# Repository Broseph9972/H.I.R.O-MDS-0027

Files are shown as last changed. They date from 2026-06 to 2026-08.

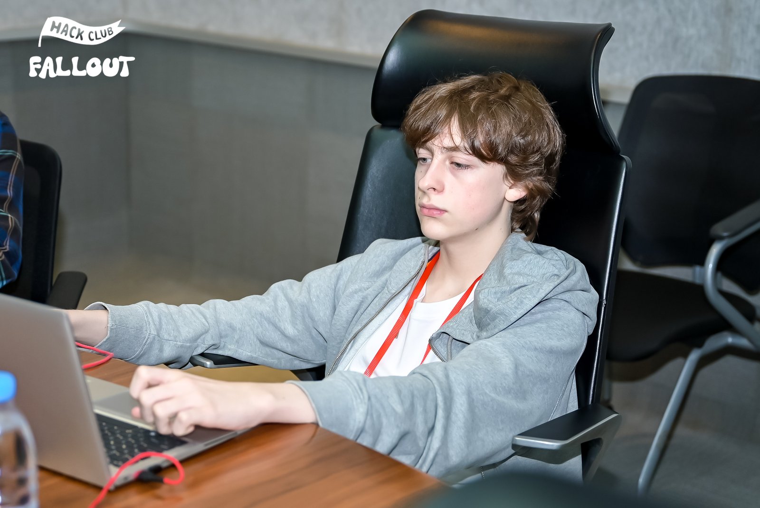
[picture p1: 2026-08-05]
3D/3d Files/2_1600_3000_gif.jpg

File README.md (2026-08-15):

# H.I.R.O-MDS-0027
a music video faithful mp3 player based on the H.I.R.O from good kid Music videos. built for Hack club fallout in about 2 weeks. My favorite Hardware project yet
---
<p align="center">
NewHiroZine


</p>
<p align="center">
  
  
  
</p>

I unironically listened to almost exclusively good kid while making this project.

---
## Why?
I've always loved good kid, and i was bored at night watching some of their music videos, and saw a scene of the H.I.R.O taken apart with a soldering iron,[^1] and realised, i could probably make that.
I cant explain how to use it yet, as i have not built it yet, but it should go something like select a song or playlist, and itll play said song or playlist. (duh)
This is my first project where i'm not very concerned about budget, as it isnt completely practical, it just needs to look as close as possible to the original. I did get rid of the arms and legs because it would make it annoying to use imho.

# Assembly

## Read through this before starting just for understanding.

  1. Solder Parts Onto the PCB. As there are many SMD Components and small capacitors, reflow soldering is recommended. Use long header pins for the screen DO NOT SOLDER THE SCREEN TO THE PCB YET.
  2. If any Through Hole parts poke into the case, like the speaker, use pliers or something to take them off. there should be indents in the case for them though.
  3. Place the PCB Onto the Main Casing. If it dosent fit, just sand the part until it does.
  4. Screw In the screen to the 4 square brackets on the main casing with M3x14 Screws.
  5. Solder the Screen Connector pins to the screen. (if gpio are short, im so sorry but i would just desolder and use jumper wires.)
  6. Plug in the battery to the JST Connector. Slide it wherever it fits, i reccomend under the screen. any lipo battery should work.
  7. (vid isnt accurate) Slide the buttons into place so that the lip dosent allow it to get pushed out.
  8. Place the Lid on Top, Turn the main casing over, and screw in 3 M3x14 Screws.
  9. (Optional) Paint it! it looks so much cooler Painted. I highly reccomend this.

### Assembly Video (its really bad)
https://github.com/user-attachments/assets/d8cce7da-2541-4a06-ba8f-5a0993665533

# Usage
The H.I.R.O has 3 inputs.
1. Button 1
2. Button 2
3. Clicky Knob

Spin the knob to cycle through the options on the screen. Click the knob to select.
Button 1 is for skipping to the next song. Hold to skip past 10s at a time in a specific song.
Button 2 is for rewinding. Click once to go to the last song. click twice to restart the song. Hold to go back 10s at a time in the song. 
# Setup
  1. Flash the Firmware for the MP3 Using arduino IDE or whichever ide you prefer
  2. Insert MicroSD Card With Music on it in Mp3 (or FLAC?) Format.
  3. Play your Music!

## Warning:
Theres a bug where the lid has a huge object inside it when 3d printing, just delete it in your slicer. i dunno why this happens.

# Bill of Materials

| Name | Qty | Reference(s) | Price (USD) | Comments | Link |
|---|-----|---|---|---|---|
| Seeed XIAO ESP32-S3 Plus | 1 | U1 | $7.59 | Main MCU module. SMD footprint (castellated). Source direct from Seeed for genuine part. | [Link](https://www.seeedstudio.com/Seeed-Studio-XIAO-ESP32S3-Plus-p-6361.html) |
| PCM5102A DAC (TSSOP-20) | 1 | U2 | $1.11 | Bare IC from LCSC (C107671). I2S DAC driving the 3.5mm headphone jack. | [Link](https://www.lcsc.com/product-detail/C107671.html) |
| MAX98357A Class-D Amplifier (TQFN-16) | 1 | U3 | $2.00 | Bare TQFN-16 3x3mm IC — NOT a breakout module. Check LCSC / DigiKey / Mouser for current price. | [Link](https://octopart.com/max98357aete+t-maxim+integrated-33346832) |
| CVS-1708 Speaker | 1 | LS1 | $4.02 | 8Ω 200mW 1.2kHz–20kHz. Same Sky (formerly CUI). DigiKey. | [Link](https://www.digikey.com/en/products/detail/same-sky-formerly-cui-devices/CVS-1708/2791829) |
| Hirose DM3AT-SF-PEJM5 microSD Slot | 1 | J1 | $1.53 | Push-push with card detect. LCSC (C114218). | [Link](https://www.lcsc.com/product-detail/SD-Card-Connectors_HRS-Hirose-DM3AT-SF-PEJM5_C114218.html) |
| CUI SJ-3523-SMT-TR 3.5mm Audio Jack | 1 | J2 | $0.88 | Horizontal SMT stereo TRS jack. DigiKey. | [Link](https://www.digikey.com/en/products/detail/cui-devices/SJ-3523-SMT-TR/281297) |
| 1×8 Pin Header 2.54mm (through-hole) | 1 | J3 | $7.99 | Screen connector for Waveshare LCD. Must use long header pins (see assembly notes). | [Link](https://www.amazon.com/whiteeeen-Break-Away-Header-Straight-Connector/dp/B0B75RKMD2) |
| JST PH S2B-PH-K 2-pin Connector | 1 | J4 | $0.11 | Battery connector. 2.0mm pitch horizontal SMT. | [Link](https://www.digikey.com/en/products/detail/jst-sales-america-inc/S2B-PH-K-S/926626) |
| Omron B3U-3100P-B Side Push Button | 2 | S1 / S2 | $1.17 | SMD side-actuated tactile. DigiKey. ×2 units needed. | [Link](https://www.digikey.com/en/products/detail/omron-electronics-inc-emc-div/B3U-3100P-B/1811780) |
| EC11 Right-Angle Rotary Encoder (w/ switch) | 1 | SW1 | $4.07 | Push-switch + encoder. Right-angle EC11. | [Link](https://www.aliexpress.us/item/3256809185234399.html) |
| Capacitor 10µF 0603 | 4 | C1 / C4 / C5 / C6 | $0.01 | X5R or X7R ceramic decoupling. Order from LCSC. | [Link](https://www.lcsc.com/search?q=10uF+0603) |
| Capacitor 100nF 0603 | 2 | C2 / C3 | $0.01 | X7R ceramic decoupling. Order from LCSC. | [Link](https://www.lcsc.com/search?q=100nF+0603) |
| Resistor 1MΩ 0603 | 1 | R1 | $0.01 | 1% tolerance preferred. Order from LCSC. | [Link](https://www.lcsc.com/search?q=1M+0603+resistor) |
| Waveshare 2.4in LCD Module | 1 | — | $18.99 | 240×320 SPI (ILI9341). Connects to J3 header. Closest size match to original H.I.R.O screen. | [Link](https://www.amazon.com/Waveshare-2-4inch-Display-Resolution-Interface/dp/B08H24H7KX) |
| LiPo Battery 3.7V | 1 | — | $9.99 | Any single-cell LiPo with JST PH 2.0mm connector. Slides under screen in case. 500mAh+ recommended. | [Link](https://www.amazon.com/Battery-Rechargeable-Lithium-Polymer-Connector/dp/B07S84SBV3) |
| M3×14 Socket Head Cap Screws | 7 | — | $6.99 | 4× screen brackets + 3× lid. Stainless steel A2. | [Link](https://a.co/d/00dNH8NP) |
| 3D Printed Main Casing | 1 | — | $0.10 | Print from Cad/ directory. Sand if needed for PCB fit (see assembly notes). | [Link](https://github.com/Broseph9972/H.I.R.O-MDS-0027/tree/main/Cad) |
| 3D Printed Lid | 1 | — | $0.10 | Print from Cad/ directory. 3× M3×14 screw holes. | [Link](https://github.com/Broseph9972/H.I.R.O-MDS-0027/tree/main/Cad) |
| Custom PCB (H.I.R.O) | 1 | — | $7.50 | Fabricate from Pcb/ gerbers. JLCPCB / PCBWay / OSH Park. | [Link](https://github.com/Broseph9972/H.I.R.O-MDS-0027/tree/main/Pcb) |
| Paint (optional) | 1 | — | $0 | Spray paint or acrylic. | — |
| **TOTAL** | — | — | **$75.38** | Qty × unit price across all lines (screws/header counted as pack price; optional paint at $0). | — |

[^1]:From [Eastside](https://www.youtube.com/watch?v=-kVTMlbAywQ) [Wall](https://www.youtube.com/watch?v=HG8WEN3SKVk)[Mimis Delivery Service](https://www.youtube.com/watch?v=hYUvI5Njbbk)

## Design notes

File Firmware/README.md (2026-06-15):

# H.I.R.O Firmware

Firmware for the H.I.R.O MDS-0027 MP3 player (Seeed XIAO ESP32-S3 Plus).

## Build & flash

1. Install **VS Code** + the **PlatformIO IDE** extension.
2. Open this `Firmware/` folder in VS Code (PlatformIO detects `platformio.ini`).
3. Plug in the XIAO over USB-C → click **Upload** (the ✓→ arrow in the PlatformIO toolbar).
4. Open the **Serial Monitor** (115200 baud) to watch boot / SD logs.

## SD card

- Format **FAT32**.
- Put your music in a top-level `/music` folder.
- Supported: **MP3, AAC, M4A, FLAC, WAV, OGG/Vorbis, Opus**.

## Controls

| Input | Action |
|---|---|
| Encoder turn | Volume |
| Encoder click | Play / Pause |
| Side button 1 | Previous track |
| Side button 2 | Next track |
| Hold side button 1 (~0.7 s) | Toggle speaker ↔ headphone |

## Code map

| File | Purpose |
|---|---|
| `src/pins.h` | Pin map (matches the KiCad schematic — single source of truth) |
| `src/LGFX_Config.h` | ST7789 display config (LovyanGFX) |
| `src/Face.h` | Programmatic animated face |
| `src/Player.h` | SD playlist + audio decode + I²S output routing |
| `src/Controls.h` | Buttons + rotary encoder |
| `src/main.cpp` | Wires it all together |

## First-hardware bring-up notes

This compiles, but it has **never run on the real board** (the board doesn't exist yet). Expect to iterate on:

1. **SPI bus sharing (display + SD).** They share SCK/MOSI/MISO. If the screen garbles during card reads, lower `freq_write` in `LGFX_Config.h` and/or the SD clock in `Player.h`.
2. **Display orientation / colors.** `setRotation`, `invert`, and `rgb_order` may need flipping once you can see it.
3. **Speaker/headphone switch.** With no jack-detect wired, output is swapped manually (hold SW1). Verify both DACs sound right.
4. **Button polarity / encoder direction.** If the encoder counts backwards, swap `PIN_ENC_A`/`PIN_ENC_B`.

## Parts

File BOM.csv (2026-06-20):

Name | Qty | Reference(s) | Price (USD) | Comments | Link
Seeed XIAO ESP32-S3 Plus | 1 | U1 | $7.59 | Main MCU module. SMD footprint (castellated). Source direct from Seeed for genuine part. | https://www.seeedstudio.com/Seeed-Studio-XIAO-ESP32S3-Plus-p-6361.html
PCM5102A DAC (TSSOP-20) | 1 | U2 | $1.11 | Bare IC from LCSC (C107671). I2S DAC driving the 3.5mm headphone jack. | https://www.lcsc.com/product-detail/C107671.html
MAX98357A Class-D Amplifier (TQFN-16) | 1 | U3 | $2 | Bare TQFN-16 3x3mm IC — NOT a breakout module. Check LCSC / DigiKey / Mouser for current price. | https://octopart.com/max98357aete+t-maxim+integrated-33346832
CVS-1708 Speaker | 1 | LS1 | $4.02 | 8Ω 200mW 1.2kHz–20kHz. Same Sky (formerly CUI). DigiKey. | https://www.digikey.com/en/products/detail/same-sky-formerly-cui-devices/CVS-1708/2791829
Hirose DM3AT-SF-PEJM5 microSD Slot | 1 | J1 | $1.53 | Push-push with card detect. LCSC (C114218). | https://www.lcsc.com/product-detail/SD-Card-Connectors_HRS-Hirose-DM3AT-SF-PEJM5_C114218.html
CUI SJ-3523-SMT-TR 3.5mm Audio Jack | 1 | J2 | $0.88 | Horizontal SMT stereo TRS jack. DigiKey. | https://www.digikey.com/en/products/detail/cui-devices/SJ-3523-SMT-TR/281297
1×8 Pin Header 2.54mm (through-hole) | 1 | J3 | $7.99 | Screen connector for Waveshare LCD. Must use long header pins (see assembly notes). | https://www.amazon.com/whiteeeen-Break-Away-Header-Straight-Connector/dp/B0B75RKMD2
JST PH S2B-PH-K 2-pin Connector | 1 | J4 | $0.11 | Battery connector. 2.0mm pitch horizontal SMT. Very cheap — order from DigiKey or LCSC. | https://www.digikey.com/en/products/detail/jst-sales-america-inc/S2B-PH-K-S/926626
Omron B3U-3100P-B Side Push Button | 2 | S1 / S2 | $1.17 | SMD side-actuated tactile. DigiKey. ×2 units needed. | https://www.digikey.com/en/products/detail/omron-electronics-inc-emc-div/B3U-3100P-B/1811780
EC11 Right-Angle Rotary Encoder (w/ switch) | 1 | SW1 | $4.07 | Push-switch + encoder. Right-angle EC11. User-sourced AliExpress link. | https://www.aliexpress.us/item/3256809185234399.html
Capacitor 10µF 0603 (×4) | 4 | C1 / C4 / C5 / C6 | $0.01 | X5R or X7R ceramic. Pennies each — order from LCSC. Search C107471 or equivalent. | https://www.lcsc.com/search?q=10uF+0603
Capacitor 100nF 0603 (×2) | 2 | C2 / C3 | $0.01 | X7R ceramic decoupling. Pennies each — order from LCSC. | https://www.lcsc.com/search?q=100nF+0603
Resistor 1MΩ 0603 (×1) | 1 | R1 | 0.01 | 1% tolerance preferred. Pennies each — order from LCSC. | https://www.lcsc.com/search?q=1M+0603+resistor
Waveshare 2.4in LCD Module | 1 | — | $18.99 | 240×320 SPI (ILI9341). Connects to J3 header. Closest size match to original H.I.R.O screen. | https://www.amazon.com/Waveshare-2-4inch-Display-Resolution-Interface/dp/B08H24H7KX
LiPo Battery 3.7V | 1 | — | $9.99 | Any single-cell LiPo with JST PH 2.0mm connector. Slides under screen in case. 500mAh+ recommended. | https://www.amazon.com/Battery-Rechargeable-Lithium-Polymer-Connector/dp/B07S84SBV3
M3×14 Socket Head Cap Screws | 7 | — | $6.99 | 4× screen brackets + 3× lid. Stainless steel A2. | https://a.co/d/00dNH8NP
3D Printed Main Casing | 1 | — | $0.10 | Print from Cad/ directory. Sand if needed for PCB fit (see assembly notes). | https://github.com/Broseph9972/H.I.R.O-MDS-0027/tree/main/Cad
3D Printed Lid | 1 | — | $0.10 | Print from Cad/ directory. 3× M3×14 screw holes. | https://github.com/Broseph9972/H.I.R.O-MDS-0027/tree/main/Cad
Custom PCB (H.I.R.O) | 1 | — | $7.50 | Fabricate from Pcb/ gerbers. JLCPCB / PCBWay / OSH Park. | https://github.com/Broseph9972/H.I.R.O-MDS-0027/tree/main/Pcb
Paint (optional) | 1 | — | $0 | Spray paint or acrylic. | _
TOTAL | — | — | $75.38 | Qty × unit price across all lines (screws/header counted as pack price; optional paint at $0). | __

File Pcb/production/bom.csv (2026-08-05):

Designator | Footprint | Quantity | Value | LCSC Part #
C1, C4, C5, C6 | 0603 | 4 | 10 µF
C2, C3 | 0603 | 2 | 100nF
J1 | microSD_HC_Hirose_DM3AT-SF-PEJM5 | 1 | Micro_SD_Card_Det_Hirose_DM3AT
J2 | Jack_3.5mm_CUI_SJ-3523-SMT_Horizontal | 1 | AudioJack3
J3 | PinHeader_1x08_P2.54mm_Vertical | 1 | Conn_01x08
J4 | JST_PH_S2B-PH-K_1x02_P2.00mm_Horizontal | 1 | Conn_01x02
LS1 | SPKR_CVS-1708 | 1 | CVS-1708
R1 | 0603 | 1 | 1M
S1, S2 | SW_SPST_B3U-3100P | 2 | B3U-3100P-B
SW1 | Right angle EC11 Rotary Encoder | 1 | RotaryEncoder_Switch
U1 | XIAO-ESP32-S3-Plus-SMD | 1 | XIAO-ESP32-S3-Plus-SMD
U2 | TSSOP-20_4.4x6.5mm_P0.65mm | 1 | PCM5102A
U3 | TQFN-16-1EP_3x3mm_P0.5mm_EP1.23x1.23mm | 1 | MAX98357A

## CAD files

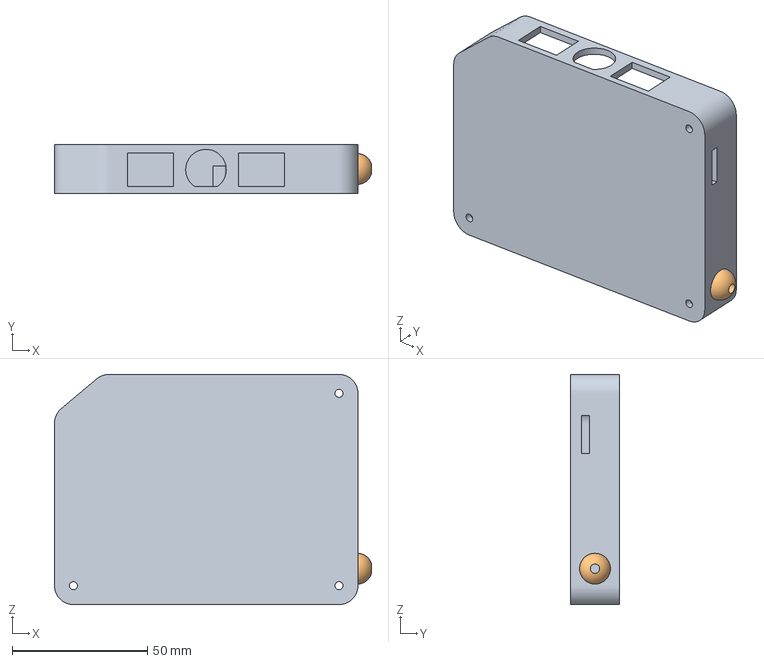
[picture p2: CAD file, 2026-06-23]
3D/3d Files/Main Casing.3mf
117.1 x 18.0 x 85.1 mm

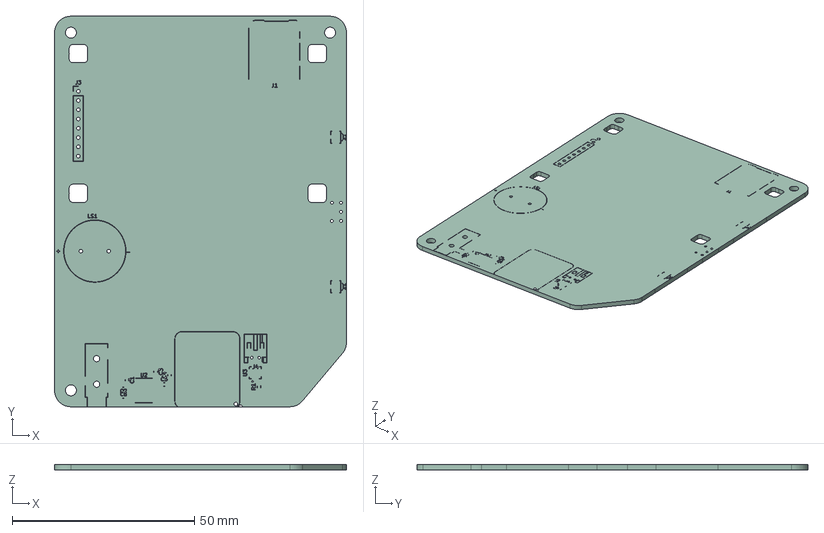
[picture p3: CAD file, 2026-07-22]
3D/3d Files/PCBNoComponents.step
80.1 x 107.1 x 1.58 mm
hiro_silkscreen
hiro_PCB

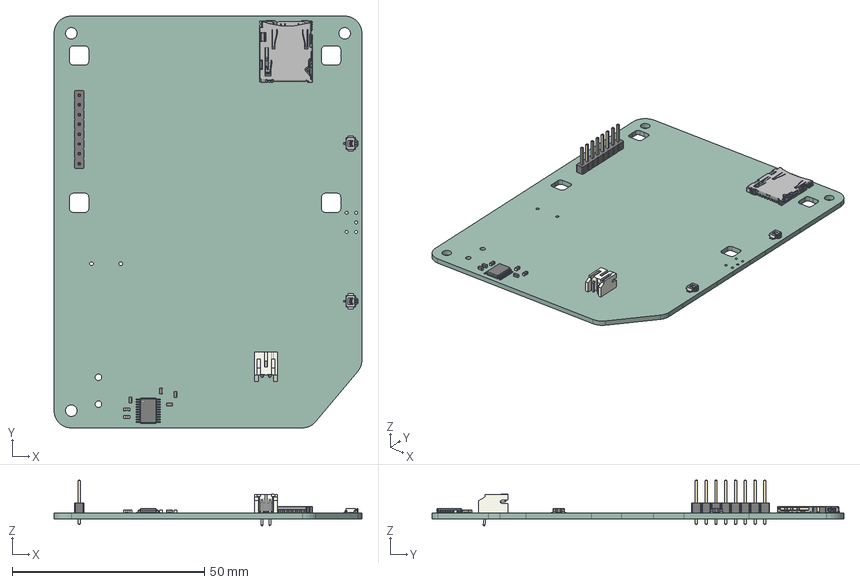
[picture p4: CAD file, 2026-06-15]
Pcb/.step
80.1 x 107.1 x 11.9 mm
TSSOP-20_4.4x6.5mm_P0.65mm
SW_SPST_B3U-3100P x 2
PinHeader_1x08_P254mm_Vertical
C_0603_1608Metric x 6
microSD_HC_Hirose_DM3AT-SF-PEJM5
JST_S2B_PH_K
hiro_PCB

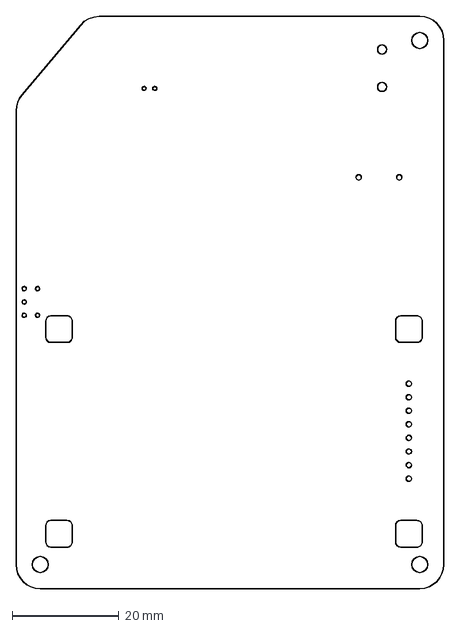
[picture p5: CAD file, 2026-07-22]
3D/3d Files/Pcb outline.dxf
80.1 x 107.1 mm

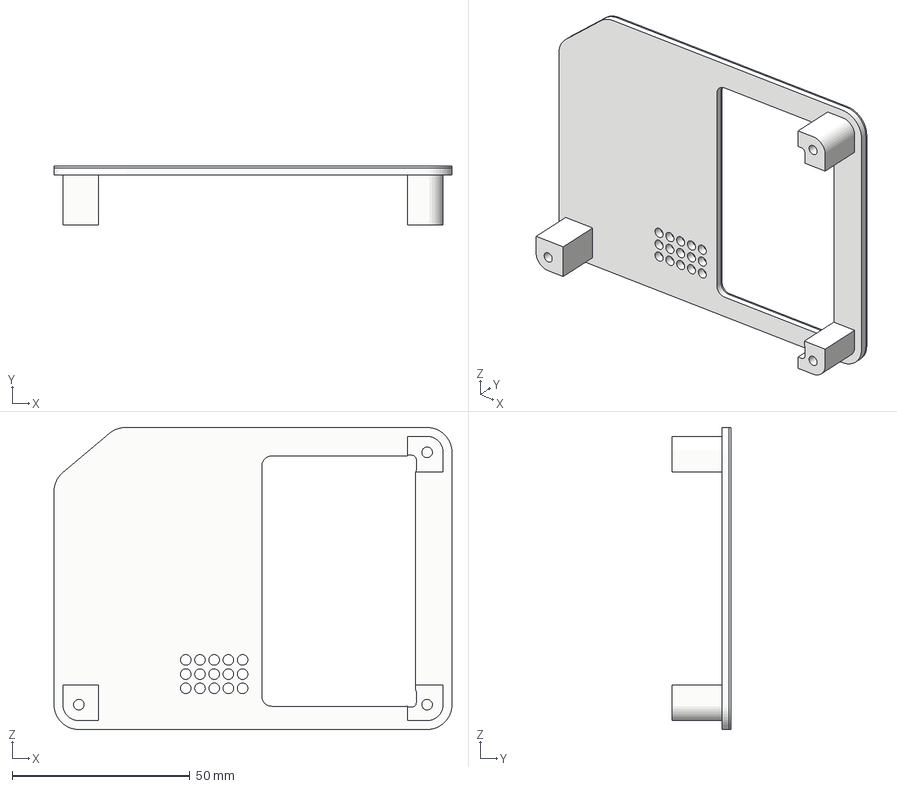
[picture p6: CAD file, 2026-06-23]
3D/3d Files/Lid.3mf
112.1 x 16.5 x 85.1 mm

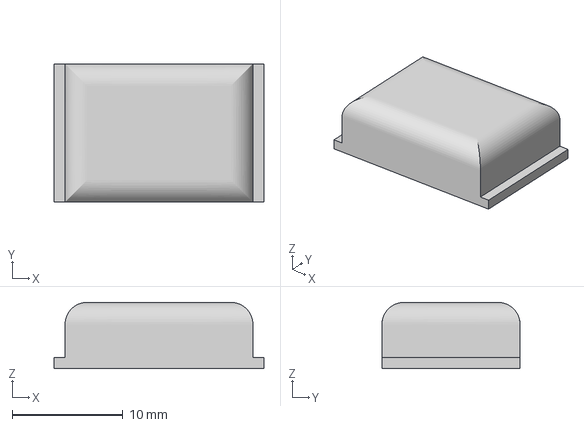
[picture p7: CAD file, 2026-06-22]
3D/3d Files/Side-Button.3mf
19.0 x 12.5 x 6.00 mm

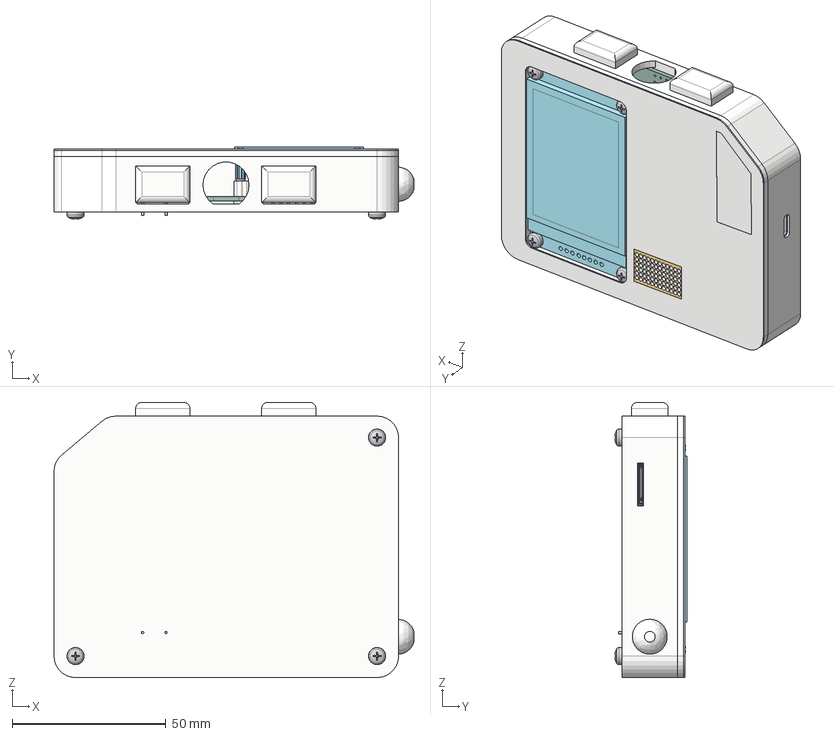
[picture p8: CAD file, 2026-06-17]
3D/3d Files/mds-0027.step
117.1 x 23.5 x 89.5 mm
K01-2
TSSOP-20_4.4x6.5mm_P0.65mm
SW_SPST_B3U-3100P x 2
CVS-1708
PinHeader_1x08_P2.54mm_Vertical
C_0603_1608Metric x 6
microSD_HC_Hirose_DM3AT-SF-PEJM5
JST_PH_S2B-PH-K_1x02_P2.00mm_Horizontal
XIAO-ESP32S3 v2
hiro_silkscreen
hiro_PCB
Main Casing
Side-Button x 2
Lid
UNE-EN ISO 7045 - M3 x 14 - H Steel 4.6 Plain x 4
ISO 7045 - M3 x 14 - H Steel 4.6 Plain x 3

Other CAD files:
3D/Source Files/Lid.f3z
3D/Source Files/Main Casing.f3d
3D/Source Files/Side-Button.f3d
3D/Source Files/mds-0027.f3z

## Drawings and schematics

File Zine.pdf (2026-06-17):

# H.I.R.O MP3 Player

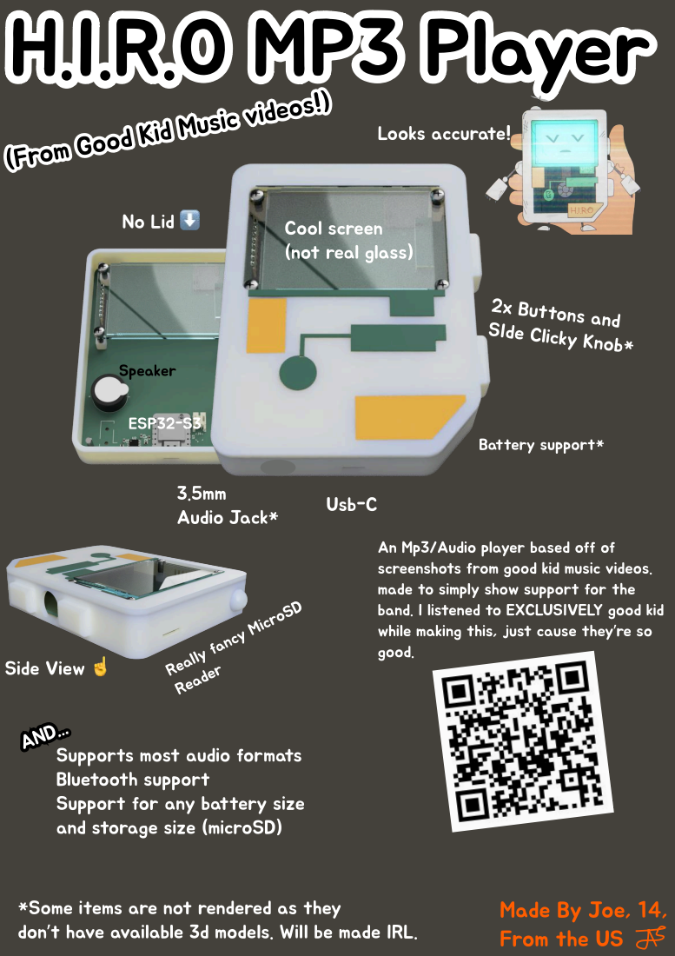
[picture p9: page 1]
Looks accurate!; Side View ☝️; Speaker; ESP32-S3; Audio Jack*; Reader; Usb-C; No Lid ⬇️; Cool screen; 2x Buttons and; Battery support*; AND...

(From Good Kid Music videos!)

(not real glass)

SIde Clicky Knob*

An Mp3/Audio player based off of
screenshots from good kid music videos.
made to simply show support for the
band. I listened to EXCLUSIVELY good kid
while making this, just cause they’re so
good.

Really fancy MicroSD

Supports most audio formats
Bluetooth support
Support for any battery size
and storage size (microSD)

*Some items are not rendered as they
don’t have available 3d models. Will be made IRL.

Made By Joe, 14,
From the US

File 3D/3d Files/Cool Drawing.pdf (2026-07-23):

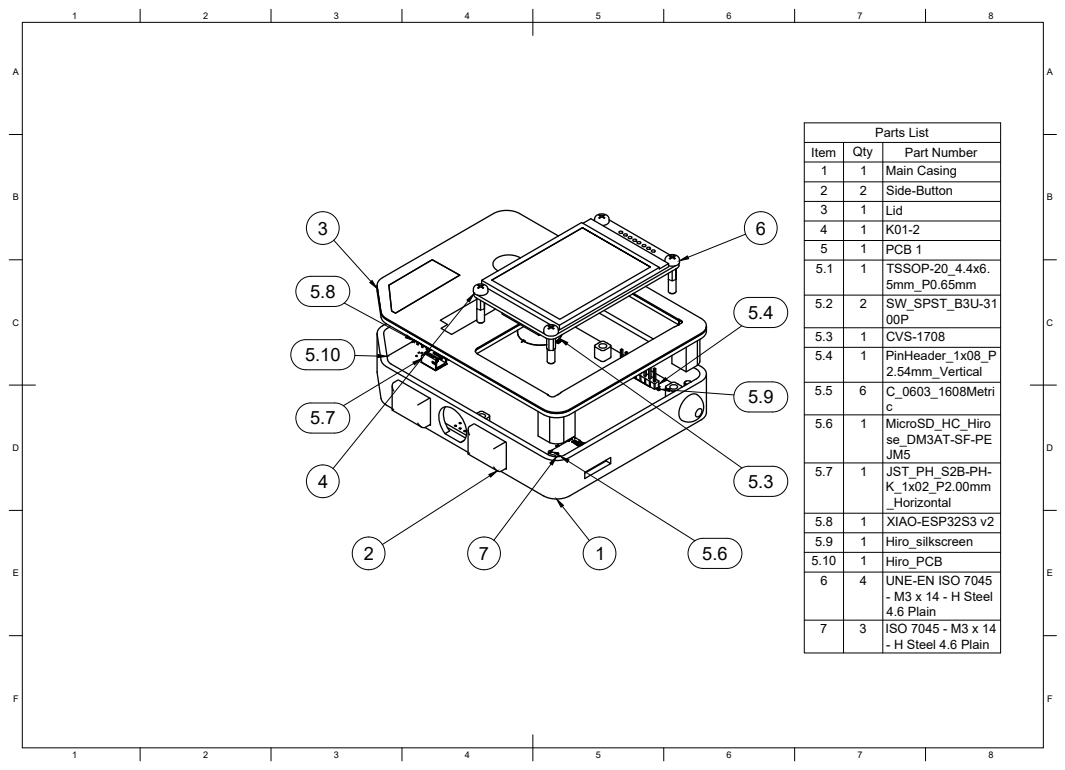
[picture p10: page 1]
8 BCDEF; ABCDEF; Parts List; Item; Qty; Part Number 1; Main Casing 2; Side-Button 3; Lid 4; PCB 1

5.1 | 1 | TSSOP-20_4.4x6. 5mm_P0.65mm

5.2 | 2 | SW_SPST_B3U-31 00P

5.3 | 1 | CVS-1708
5.4 | 1 | PinHeader_1x08_P 2.54mm_Vertical

5.5 | 6 | C_0603_1608Metri c

5.6 | 1 | MicroSD_HC_Hiro se_DM3AT-SF-PE JM5

5.7 | 1 | JST_PH_S2B-PH-K_1x02_P2.00mm _Horizontal

5.8 | 1 | XIAO-ESP32S3 v2
5.9 | 1 | Hiro_silkscreen
5.10 | 4 1 | Hiro_PCB 6 UNE-EN ISO 7045

3 | - M3 x 14 - H Steel ISO 7045 - M3 x 14 4.6 Plain 7

- H Steel 4.6 Plain

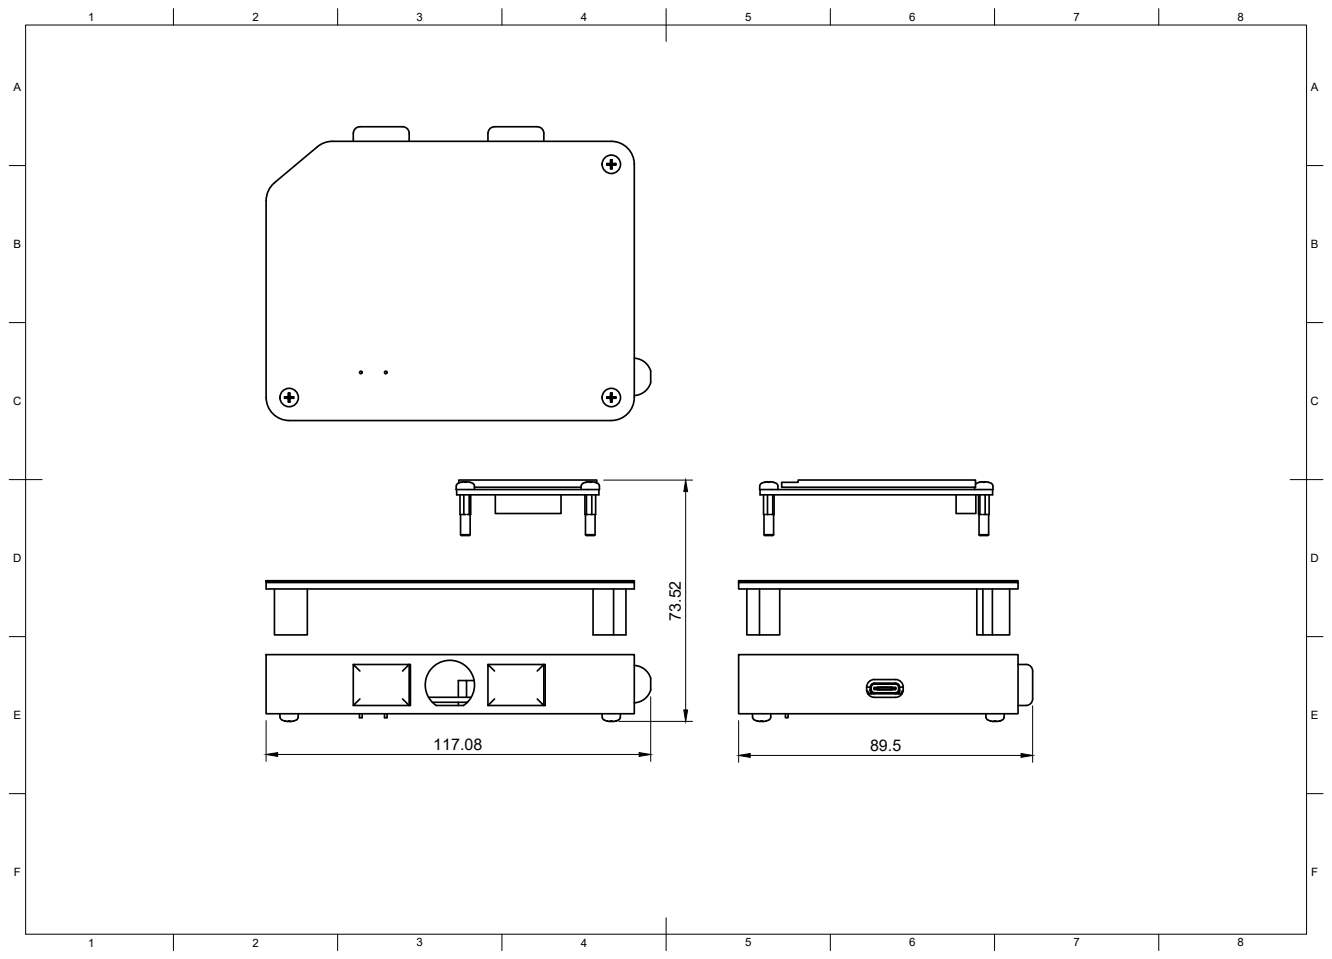
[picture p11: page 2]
8 BCDEF; ABCDEF

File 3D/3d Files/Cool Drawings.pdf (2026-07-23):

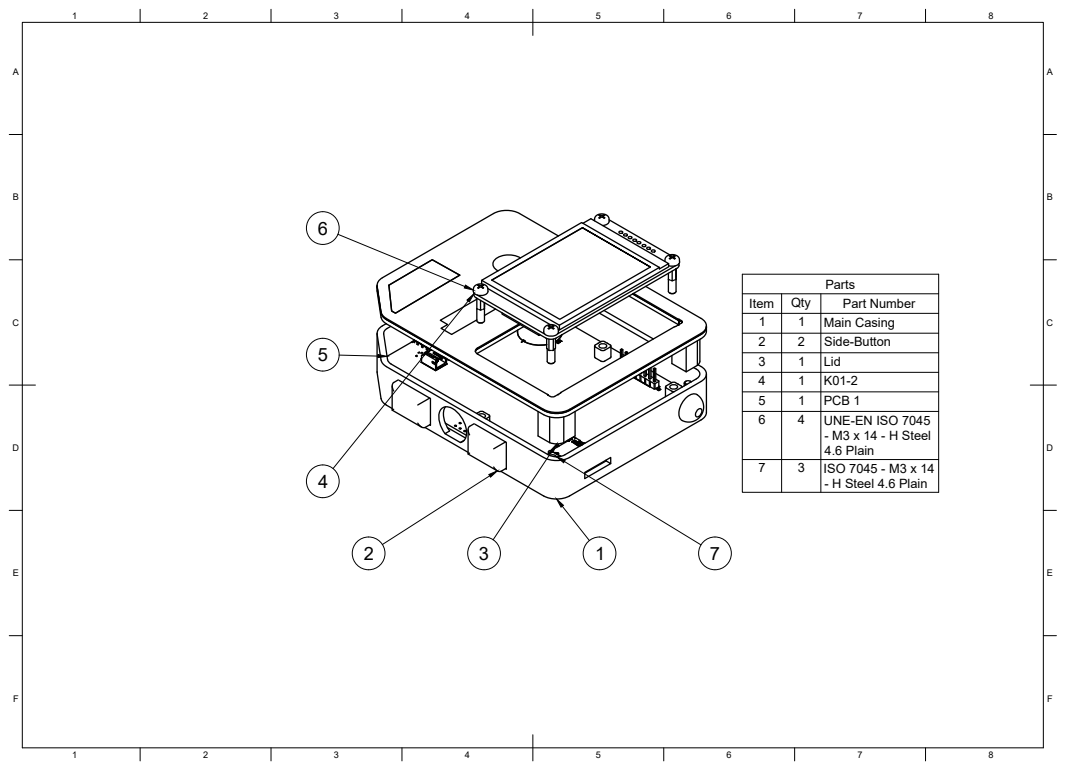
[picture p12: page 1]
8 BCDEF; ABCDEF; Item; Qty; Part Number 1; Main Casing 2; Side-Button 3; Lid 4; PCB 1 6; UNE-EN ISO 7045; - M3 x 14 - H Steel; 4.6 Plain 7; ISO 7045 - M3 x 14; - H Steel 4.6 Plain 546

8 BCDEF; ABCDEF

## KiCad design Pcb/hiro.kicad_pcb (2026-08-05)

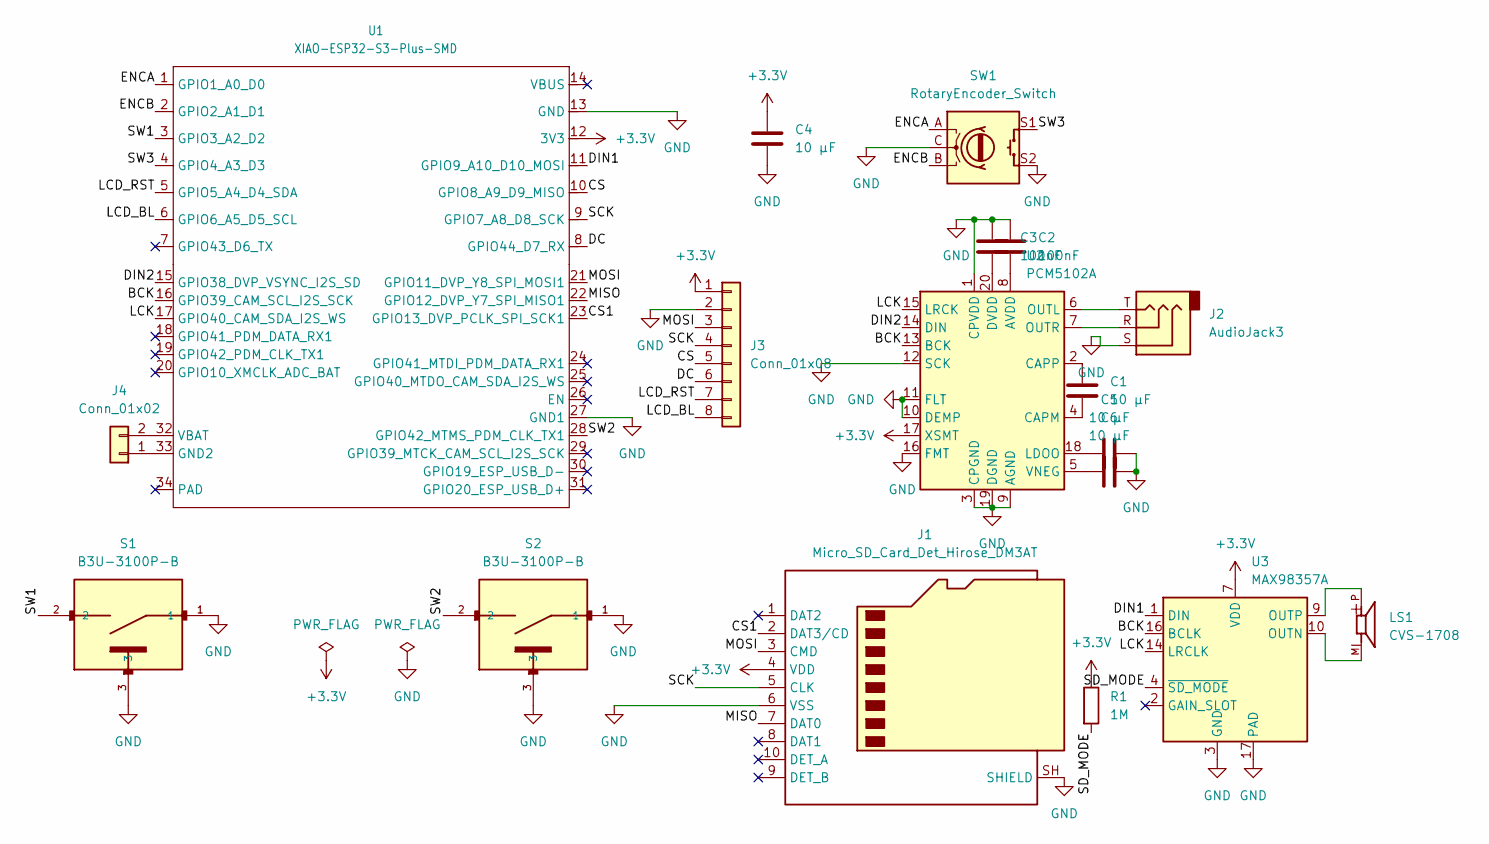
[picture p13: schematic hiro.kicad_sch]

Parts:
C1, C4, C5, C6: 10 µF; C_0603_1608Metric_Pad1.08x0.95mm_HandSolder
C2, C3: 100nF; C_0603_1608Metric_Pad1.08x0.95mm_HandSolder
J1: Micro_SD_Card_Det_Hirose_DM3AT; microSD_HC_Hirose_DM3AT-SF-PEJM5
J2: AudioJack3; Jack_3.5mm_CUI_SJ-3523-SMT_Horizontal
J3: Conn_01x08; PinHeader_1x08_P2.54mm_Vertical
J4: Conn_01x02; JST_PH_S2B-PH-K_1x02_P2.00mm_Horizontal
LS1: CVS-1708; SPKR_CVS-1708
R1: 1M; R_0603_1608Metric_Pad0.98x0.95mm_HandSolder
S1, S2: B3U-3100P-B; SW_SPST_B3U-3100P
SW1: RotaryEncoder_Switch; Right angle EC11 Rotary Encoder
U1: XIAO-ESP32-S3-Plus-SMD
U2: PCM5102A; TSSOP-20_4.4x6.5mm_P0.65mm
U3: MAX98357A; TQFN-16-1EP_3x3mm_P0.5mm_EP1.23x1.23mm

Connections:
+3.3V: C4.1, J1.4 (VDD), J3.1, R1.1, U1.12 (3V3), U2.17 (XSMT), U3.7 (VDD), U3.8 (VDD)
/BCK: U1.16 (GPIO39_CAM_SCL_I2S_SCK), U2.13 (BCK), U3.16 (BCLK)
/CS: J3.5, U1.10 (GPIO8_A9_D9_MISO)
/CS1: J1.2 (DAT3/CD), U1.23 (GPIO13_DVP_PCLK_SPI_SCK1)
/DC: J3.6, U1.8 (GPIO44_D7_RX)
/DIN1: U1.11 (GPIO9_A10_D10_MOSI), U3.1 (DIN)
/DIN2: U1.15 (GPIO38_DVP_VSYNC_I2S_SD), U2.14 (DIN)
/ENCA: SW1.A, U1.1 (GPIO1_A0_D0)
/ENCB: SW1.B, U1.2 (GPIO2_A1_D1)
/LCD_BL: J3.8, U1.6 (GPIO6_A5_D5_SCL)
/LCD_RST: J3.7, U1.5 (GPIO5_A4_D4_SDA)
/LCK: U1.17 (GPIO40_CAM_SDA_I2S_WS), U2.15 (LRCK), U3.14 (LRCLK)
/MISO: J1.7 (DAT0), U1.22 (GPIO12_DVP_Y7_SPI_MISO1)
/MOSI: J1.3 (CMD), J3.3, U1.21 (GPIO11_DVP_Y8_SPI_MOSI1)
/SCK: J1.5 (CLK), J3.4, U1.9 (GPIO7_A8_D8_SCK)
/SD_MODE: R1.2, U3.4 (~SD_MODE)
/SW1: S1.2, U1.3 (GPIO3_A2_D2)
/SW2: S2.2, U1.28 (GPIO42_MTMS_PDM_CLK_TX1)
/SW3: SW1.S1, U1.4 (GPIO4_A3_D3)
GND: C2.1, C3.1, C4.2, C5.2, C6.2, J1.6 (VSS), J1.SH (SHIELD), J2.S, J3.2, S1.1, S1.3, S2.1, S2.3, SW1.C, SW1.S2, U1.13 (GND), U1.27 (GND1), U2.1 (CPVDD), U2.3 (CPGND), U2.9 (AGND), U2.10 (DEMP), U2.11 (FLT), U2.12 (SCK), U2.16 (FMT), U2.19 (DGND), U3.3 (GND), U3.11 (GND), U3.15 (GND), U3.17 (PAD)
unnamed: J4.1, U1.33 (GND2)
unnamed: J4.2, U1.32 (VBAT)
unnamed: C2.2, U2.8 (AVDD)
unnamed: C1.2, U2.4 (CAPM)
unnamed: C1.1, U2.2 (CAPP)
unnamed: C3.2, U2.20 (DVDD)
unnamed: C5.1, U2.18 (LDOO)
unnamed: J2.T, U2.6 (OUTL)
unnamed: J2.R, U2.7 (OUTR)
unnamed: C6.1, U2.5 (VNEG)
unnamed: LS1.M, U3.10 (OUTN)
unnamed: LS1.P, U3.9 (OUTP)

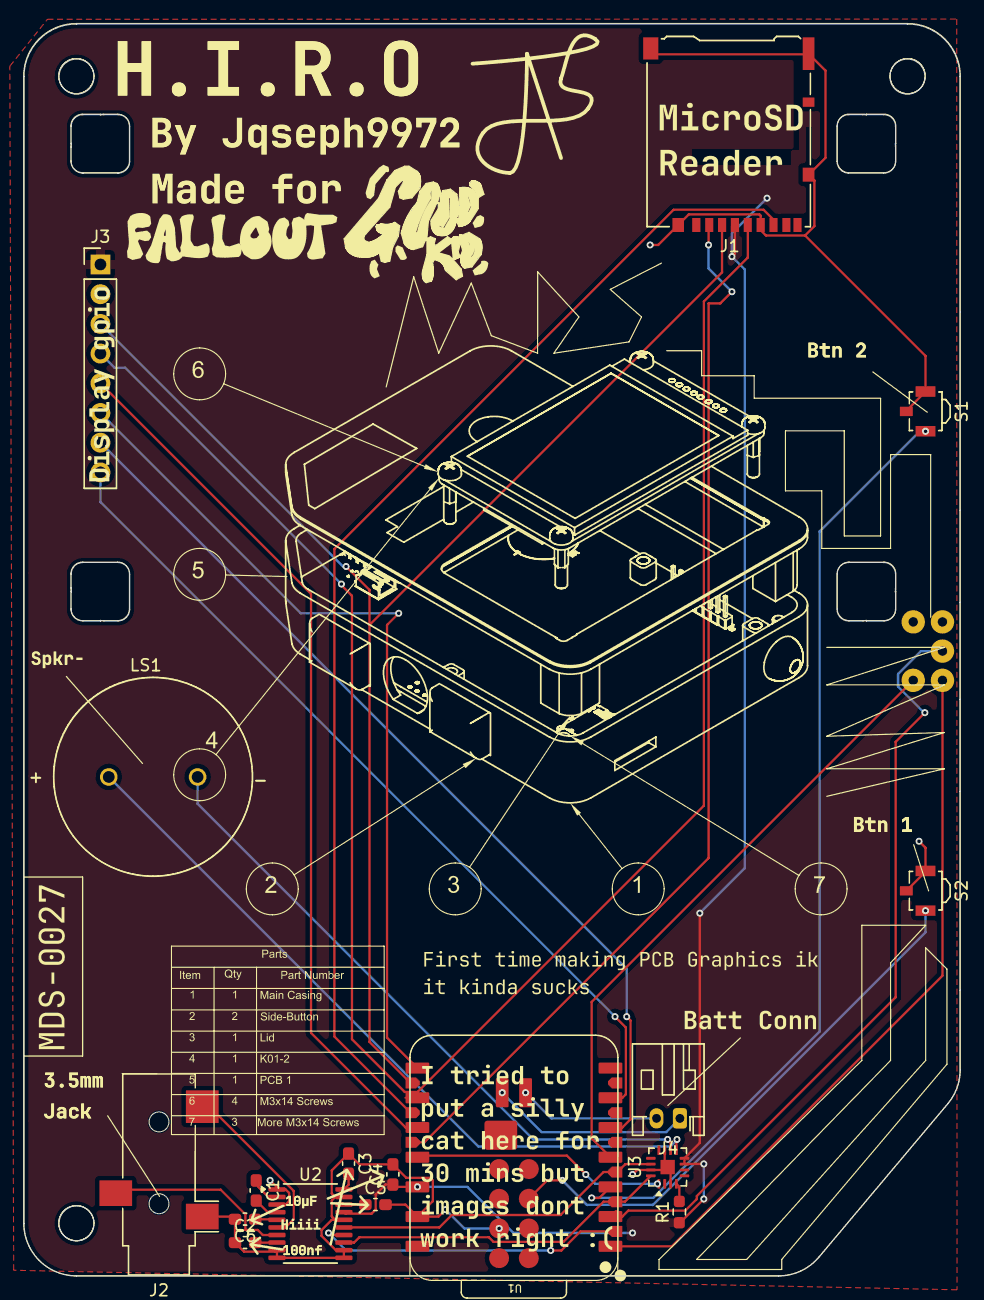
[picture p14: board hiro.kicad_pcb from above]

Board: 2 copper layers, 80.1 x 107.1 mm, 18 parts (0 on the bottom side), 32 nets.

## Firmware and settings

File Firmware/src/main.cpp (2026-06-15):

// main.cpp — H.I.R.O MDS-0027 firmware entry point.
//
// Controls:
//   • Encoder turn  -> volume
//   • Encoder click -> play / pause
//   • Side button 1 -> previous track
//   • Side button 2 -> next track
//   • Hold button 1 -> toggle speaker / headphone output
//
// First bring-up order on real hardware: (1) screen shows a face, (2) SD mounts &
// lists tracks over serial, (3) audio plays to the speaker. Tackle them in that order.
#include <Arduino.h>
#include "LGFX_Config.h"
#include "Face.h"
#include "Player.h"
#include "Controls.h"

static LGFX     lcd;
static Face     face(lcd);
static Player   player;
static Controls controls;

Player* gPlayer = nullptr;   // for the audio end-of-file callback below

// ESP32-audioI2S fires this when a track finishes -> auto-advance.
void audio_eof_mp3(const char* info) { if (gPlayer) gPlayer->onTrackEnd(); }

void setup() {
  Serial.begin(115200);
  delay(200);
  Serial.println("\nH.I.R.O MDS-0027 booting...");

  face.begin();                 // brings up the display + draws the face
  controls.begin();

  gPlayer = &player;
  if (player.begin() && player.trackCount() > 0) {
    player.playIndex(0);        // kick off the first track so there's something to hear
  } else {
    Serial.println("[main] No SD / no tracks — running face-only.");
  }
}

void loop() {
  player.loop();                // MUST run often to keep audio fed

  InputEvents ev = controls.poll();
  if (ev.encDelta > 0)      { player.volumeUp();   face.glance(0.6f); }
  else if (ev.encDelta < 0) { player.volumeDown(); face.glance(-0.6f); }
  if (ev.encClick)          { player.togglePause(); }
  if (ev.sw1)               { player.prev(); face.glance(-1.f); }
  if (ev.sw2)               { player.next(); face.glance(1.f); }

  // Hold SW1 (~700 ms) -> swap speaker/headphone.
  static uint32_t sw1Down = 0;
  if (digitalRead(PIN_BTN_SW1) == LOW) {
    if (!sw1Down) sw1Down = millis();
    else if (millis() - sw1Down > 700) { player.toggleOutput(); sw1Down = 0; }
  } else sw1Down = 0;

  // Reflect playback state on the face.
  if (player.isPaused())      face.setMood(Face::Mood::Paused);
  else if (player.isActive()) face.setMood(Face::Mood::Playing);
  else                        face.setMood(Face::Mood::Idle);

  face.update();                // self-paced ~30 fps, non-blocking
}

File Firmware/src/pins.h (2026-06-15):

// pins.h — H.I.R.O MDS-0027 pin map
// These come straight from the verified KiCad schematic (Pcb/hiro.kicad_sch).
// If you ever re-route the board, update these to match.
#pragma once

// ---- I2S audio (shared bit/word clock; one data line per DAC) ----
#define PIN_I2S_BCLK   39   // bit clock  -> MAX98357A + PCM5102A
#define PIN_I2S_LRCK   40   // word/LR clock -> both
#define PIN_I2S_DOUT_SPK  9    // data -> MAX98357A (built-in speaker)
#define PIN_I2S_DOUT_HP   38   // data -> PCM5102A (3.5mm headphone jack)

// ---- Shared SPI bus (display + microSD) ----
#define PIN_SPI_SCK    7
#define PIN_SPI_MOSI   11
#define PIN_SPI_MISO   12

// ---- ST7789 2.4" display (Waveshare, 240x320) ----
#define PIN_LCD_CS     8
#define PIN_LCD_DC     44
#define PIN_LCD_RST    5
#define PIN_LCD_BL     6    // backlight (PWM-dimmable)

// ---- microSD card ----
#define PIN_SD_CS      13

// ---- Controls (all active-LOW; wired button -> GND, use INPUT_PULLUP) ----
#define PIN_BTN_SW1    3    // side button 1
#define PIN_BTN_SW2    42   // side button 2
#define PIN_ENC_SW     4    // rotary encoder push (was "SW3")
#define PIN_ENC_A      1    // encoder quadrature A
#define PIN_ENC_B      2    // encoder quadrature B

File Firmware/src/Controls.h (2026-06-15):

// Controls.h — 2 side buttons + EC11 rotary encoder (with push switch).
// All inputs are active-LOW (wired to GND), read with internal pull-ups.
// poll() returns the events that happened since the last call.
#pragma once
#include <Arduino.h>
#include "pins.h"

struct InputEvents {
  bool sw1      = false;   // side button 1  (falling edge)
  bool sw2      = false;   // side button 2
  bool encClick = false;   // encoder push
  int  encDelta = 0;       // detents turned: +cw / -ccw
};

class Controls {
public:
  void begin() {
    pinMode(PIN_BTN_SW1, INPUT_PULLUP);
    pinMode(PIN_BTN_SW2, INPUT_PULLUP);
    pinMode(PIN_ENC_SW,  INPUT_PULLUP);
    pinMode(PIN_ENC_A,   INPUT_PULLUP);
    pinMode(PIN_ENC_B,   INPUT_PULLUP);
    _encState = readAB();
  }

  InputEvents poll() {
    InputEvents ev;
    ev.sw1      = fell(PIN_BTN_SW1, _s1);
    ev.sw2      = fell(PIN_BTN_SW2, _s2);
    ev.encClick = fell(PIN_ENC_SW, _sw);
    ev.encDelta = readEncoder();
    return ev;
  }

private:
  struct Btn { bool last = true; uint32_t t = 0; };

  // Debounced falling-edge detector (true once per press).
  bool fell(uint8_t pin, Btn& b) {
    bool now = digitalRead(pin);
    uint32_t ms = millis();
    if (now != b.last && ms - b.t > 25) {
      b.t = ms;
      bool pressed = (b.last == true && now == false);
      b.last = now;
      return pressed;
    }
    b.last = now;
    return false;
  }

  uint8_t readAB() { return (digitalRead(PIN_ENC_A) << 1) | digitalRead(PIN_ENC_B); }

  // Quadrature decode via transition lookup table; accumulates to whole detents.
  int readEncoder() {
    static const int8_t tbl[16] = {0,-1,1,0, 1,0,0,-1, -1,0,0,1, 0,1,-1,0};
    uint8_t s = readAB();
    int8_t move = tbl[(_encState << 2) | s];
    _encState = s;
    _encAccum += move;
    int detent = 0;
    if (_encAccum >= 4)      { detent =  1; _encAccum = 0; }   // 4 transitions per detent
    else if (_encAccum <= -4){ detent = -1; _encAccum = 0; }
    return detent;
  }

  Btn _s1, _s2, _sw;
  uint8_t _encState = 0;
  int     _encAccum = 0;
};

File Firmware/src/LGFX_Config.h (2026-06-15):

// LGFX_Config.h — LovyanGFX panel definition for the Waveshare 2.4" ST7789 (240x320)
// on the shared SPI bus. The microSD shares this bus too (see Player.h), so we let
// LovyanGFX own SPI2_HOST and the SD library reuses the same pins/host.
#pragma once

#define LGFX_USE_V1
#include <LovyanGFX.hpp>
#include "pins.h"

class LGFX : public lgfx::LGFX_Device {
  lgfx::Panel_ST7789  _panel;
  lgfx::Bus_SPI       _bus;
  lgfx::Light_PWM     _light;

public:
  LGFX() {
    { // SPI bus
      auto cfg = _bus.config();
      cfg.spi_host    = SPI2_HOST;   // FSPI on the ESP32-S3
      cfg.spi_mode    = 0;
      cfg.freq_write  = 40000000;    // 40 MHz; drop to 27 MHz if you see glitches on real hw
      cfg.freq_read   = 16000000;
      cfg.spi_3wire   = false;
      cfg.use_lock    = true;        // needed because microSD shares this bus
      cfg.dma_channel = SPI_DMA_CH_AUTO;
      cfg.pin_sclk    = PIN_SPI_SCK;
      cfg.pin_mosi    = PIN_SPI_MOSI;
      cfg.pin_miso    = PIN_SPI_MISO;
      cfg.pin_dc      = PIN_LCD_DC;
      _bus.config(cfg);
      _panel.setBus(&_bus);
    }
    { // ST7789 panel
      auto cfg = _panel.config();
      cfg.pin_cs        = PIN_LCD_CS;
      cfg.pin_rst       = PIN_LCD_RST;
      cfg.pin_busy      = -1;
      cfg.panel_width   = 240;
      cfg.panel_height  = 320;
      cfg.offset_x      = 0;
      cfg.offset_y      = 0;
      cfg.readable      = false;
      cfg.invert        = true;      // ST7789 panels usually need inversion on
      cfg.rgb_order     = false;
      cfg.bus_shared    = true;      // share SPI with the SD card
      _panel.config(cfg);
    }
    { // backlight (PWM so the face can dim / pulse)
      auto cfg = _light.config();
      cfg.pin_bl      = PIN_LCD_BL;
      cfg.invert      = false;
      cfg.freq        = 12000;
      cfg.pwm_channel = 7;
      _light.config(cfg);
      _panel.setLight(&_light);
    }
    setPanel(&_panel);
  }
};

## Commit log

2026-06-06 schematic parts
    added a really nice microsd card slot, an esp32-s3, and an audio jack.
    [hiro.kicad_sch]
2026-06-06 sooooooooooooooo much work
    [hiro.kicad_pcb, hiro.kicad_sch]
2026-06-07 THE OUTLINE WORKS YAYYY
    [hiro.kicad_pcb, hiro.kicad_sch]
2026-06-07 Some stuff
    it is def broken rn will fix laterrr
    [hiro.kicad_sch]
2026-06-07 New wiring cause botato is awesome
    [hiro.kicad_pcb]
2026-06-07 got a sideway switch working correctly.
    [hiro.kicad_pcb, hiro.kicad_sch]
2026-06-08 Speaker + Speaker amp and 3d model
    [hiro.kicad_pcb, hiro.kicad_sch]
2026-06-09 Some stuffs
    [hiro.kicad_pcb, hiro.kicad_sch]
2026-06-09 New Speaker, some new cad, other stuff, renders, etc
    [hiro.kicad_pcb, hiro.kicad_sch]
2026-06-11 Placed The screen connector in (almost) the right spot
    [Sketch7.dxf, hiro.kicad_pcb]
2026-06-12 Lots of wiring
    [hiro.kicad_pcb]
2026-06-12 Final PCB (rev1)
    [hiro.kicad_pcb]
2026-06-15 moved speaker
    It now lines up with the like left square thingy in the art.
    [hiro.kicad_pcb]
2026-06-15 step file
    [.step]
2026-06-15 Some changes i forget
    [hiro.kicad_pcb]
2026-06-15 FINAL PCB FINAL PCB FINAL PCB
    [hiro.kicad_pcb, hiro.kicad_sch]
2026-06-17 Bom table in readme
2026-06-17 Gerbers for pcb
    [hiro-B_Cu.gbr, hiro-B_Mask.gbr, hiro-B_Paste.gbr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]
2026-06-17 didnt add csv cause readme brooo
    [BOM.csv, hiro.kicad_pcb]
2026-06-17 CAD FILE EXPORT
    [Lid.3mf, Lid.f3z, Main Casing.3mf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]
2026-06-17 gerbers and bom
    [BOM.csv]
2026-06-17 pcb price
    [BOM.csv]
2026-06-20 added totals to bom and readme bom
    [BOM.csv]
2026-06-22 new cad
    [Lid.3mf, Lid.f3z, Main Casing.3mf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]
2026-06-23 Made cad work
    Fixed an issue where the screw holes overlapped with the other screw holes so the case wont assemble.
    [Lid.3mf, Main Casing.3mf, Main Casing.f3d]
2026-06-23 also this
    [Lid.f3z]
2026-07-22 files yayy
    [PCBNoComponents.step, Pcb outline.dxf]
2026-08-04 pcb silkscreen
    [hiro.kicad_pcb]
2026-08-05 Uh final stuffs i bought emm yayyyy
    idk how that pic got there i was sending to my friend idk
    [bom.csv, designators.csv, hiro.kicad_pcb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]
